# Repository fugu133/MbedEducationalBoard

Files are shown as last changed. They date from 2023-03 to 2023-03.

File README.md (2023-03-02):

# Mbed Educational Board
マイコン教育用として開発した基板になります．  
ベースは[mbed LPC1768](https://os.mbed.com/platforms/mbed-LPC1768/)でmbed OSを使ってプロトタイピング開発が可能です.  

サイズが75mm x 55mmの基板に以下の機能が搭載されています．
* タクトスイッチ x4
* アナログボリューム x3
* 完全絶縁のモータドライバ x2
* 6軸IMUセンサ x1
* トランスデューサ x1
* USBコネクタ x1
* GPIO x5 (内2つはI2C)

初学者向けに周辺機器を動かすための[ドライバ](https://github.com/fugu133/MbedEducationalBoard/tree/main/mbed/flib)を用意しているので簡単に扱えるかと思います．

比較的簡単にはんだ付けができるよう一部モジュール基板を使用しています．  
この基板一枚で簡単なロボットも作ることができます！



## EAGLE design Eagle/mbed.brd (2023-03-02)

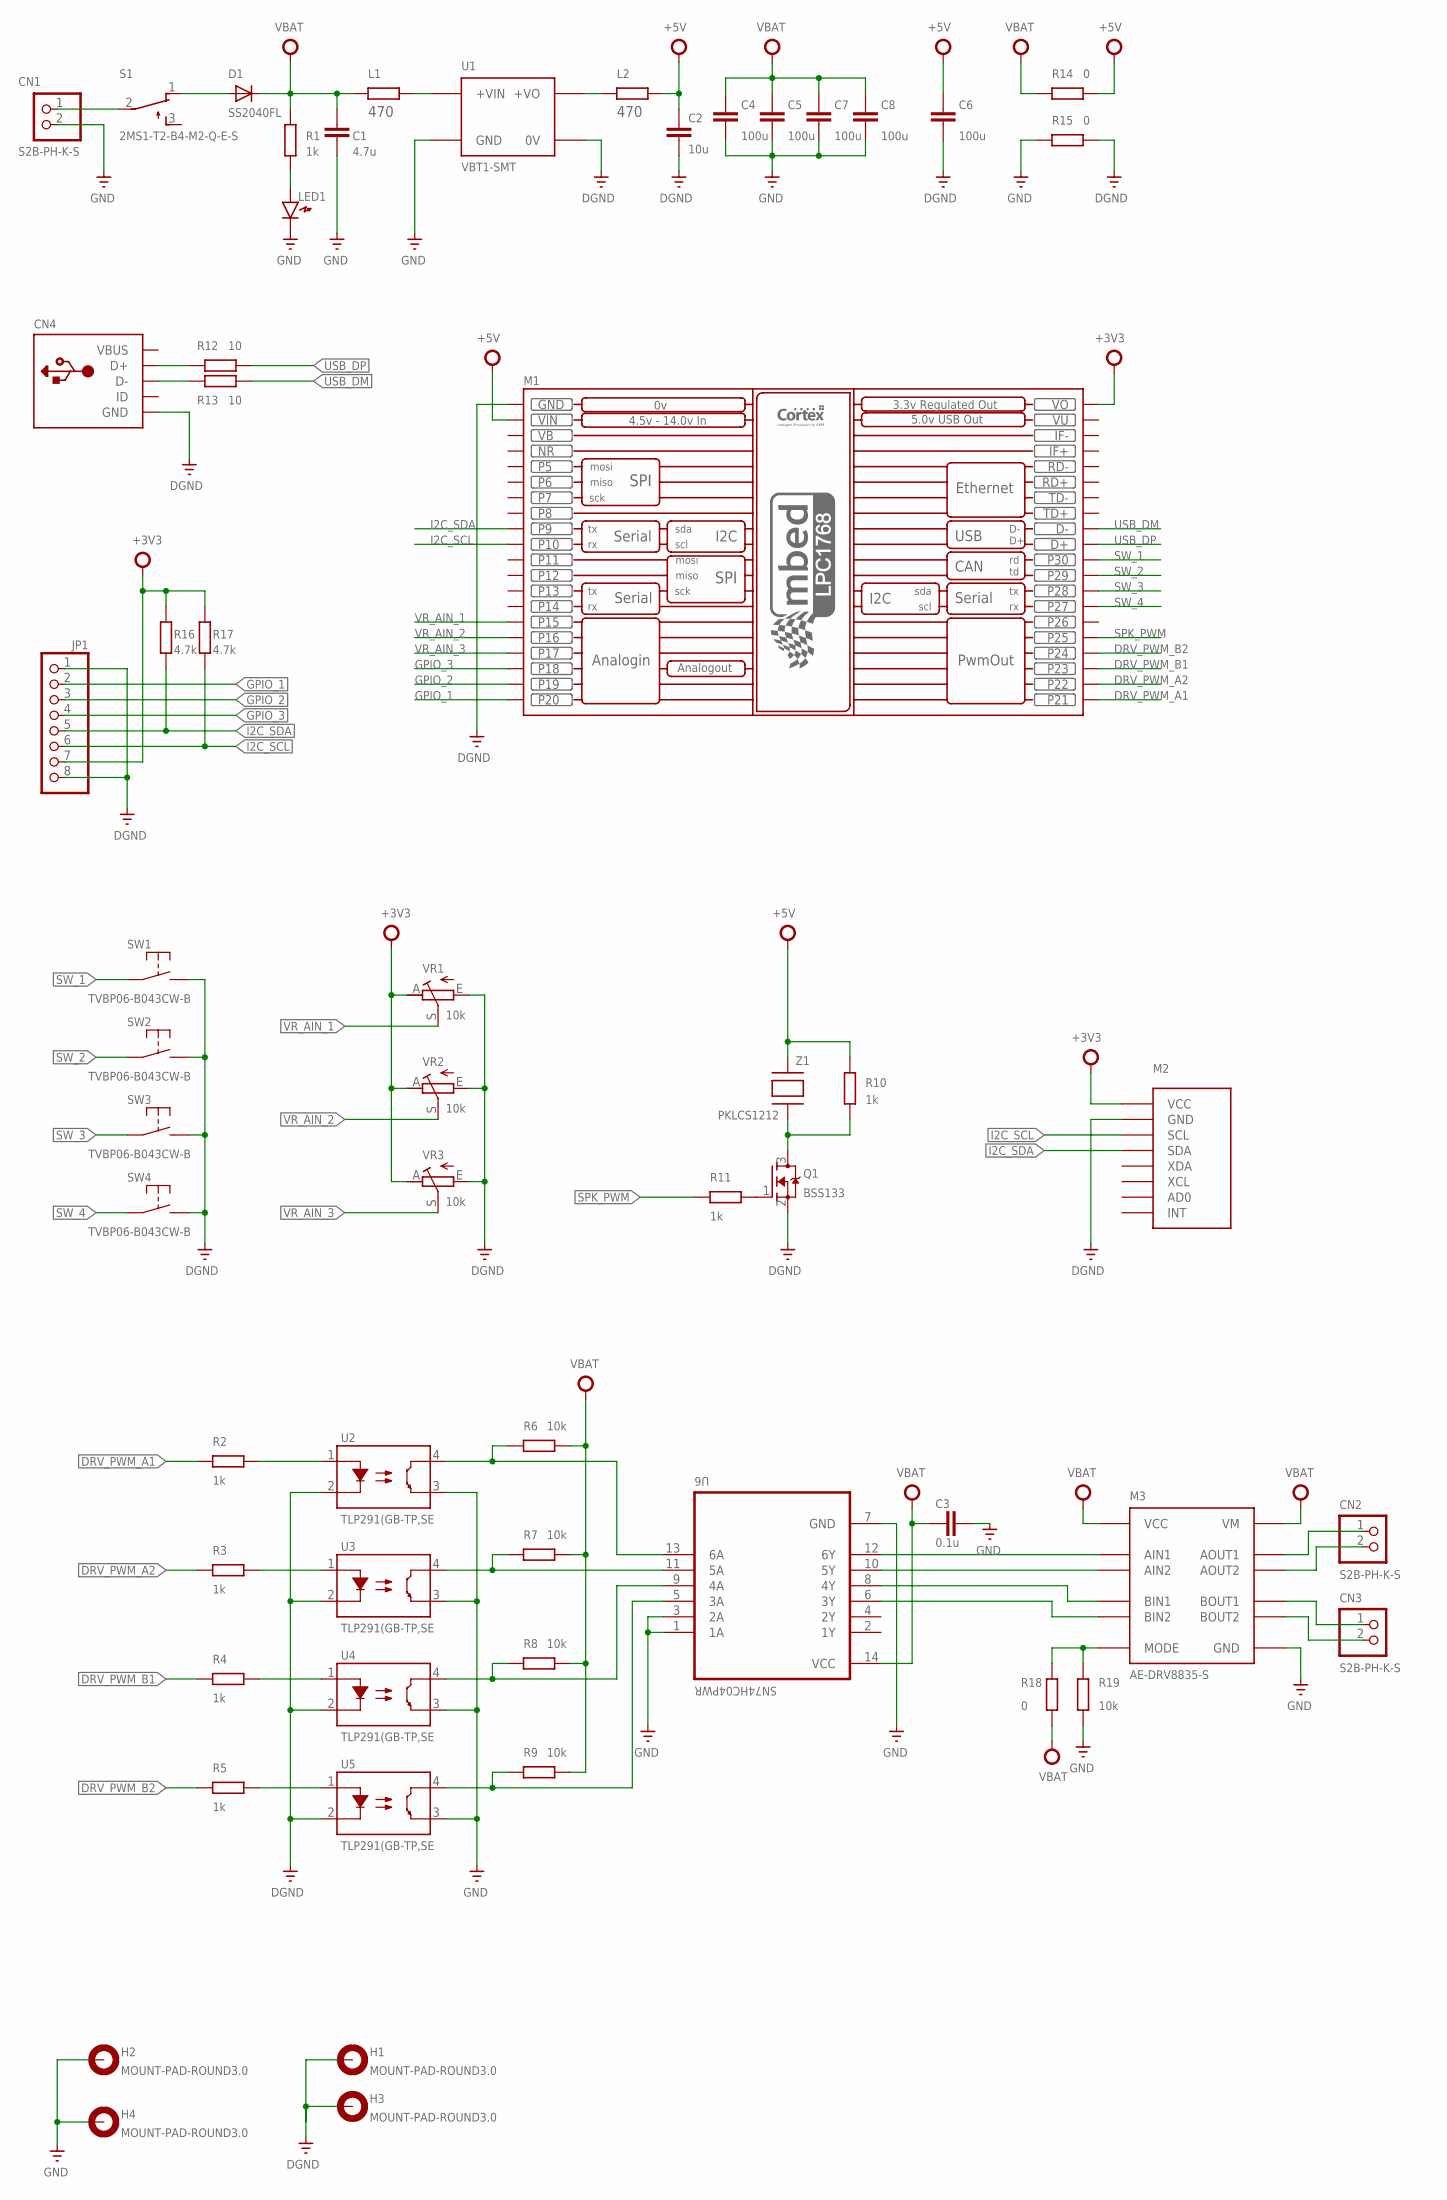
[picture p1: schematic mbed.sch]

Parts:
C1: 4.7u; C0603K
C2: 10u; C0603K
C3: 0.1u; C0603K
C4, C5, C6, C7, C8: 100u; C1206K
CN1, CN2, CN3: S2B-PH-K-S; JST-PH-2-THM-RA
CN4: USBMINIB; USB-MINIB
D1: SS2040FL; SOD-123
H1, H2, H3, H4: MOUNT-PAD-ROUND3.0; 3,0-PAD
JP1: PINHD-1X8BIG; 1X08-BIG
L1, L2: 470; R0603
LED1: LED_1608
M1: MBED_NXP_LPC1768; MBED-KIT
M2: MPU6050(GY-521); MPU6050
M3: AE-DRV8835-S; DIL12
Q1: BSS133; SOT23
R1, R2, R3, R4, R5, R10, R11: 1k; R0603
R6, R7, R8, R9, R19: 10k; R0603
R12, R13: 10; R0603
R14, R15, R18: 0; R0603
R16, R17: 4.7k; R0603
S1: 2MS1-T2-B4-M2-Q-E-S; TL3XPO
SW1, SW2, SW3, SW4: TVBP06-B043CW-B; SW1
U1: VBT1-SMT
U2, U3, U4, U5: TLP291(GB-TP,SE; SOIC127P700X220-4N
U6: SN74HC04PWR; SOP65P640X120-14N
VR1, VR2, VR3: 10k; VR-BOURNS
Z1: PKLCS1212

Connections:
+3V3: JP1.7, M1.VOUT (VO), M2.P$1 (VCC), R16.2, R17.2, VR1.A, VR2.A, VR3.A
+5V: C2.1, C6.1, L2.2, M1.VIN, R10.2, R14.1, Z1.P$2
DGND: C2.2, C6.2, CN4.GND, H1.B3,0, H3.B3,0, JP1.1, JP1.8, M1.GND, M2.P$2 (GND), Q1.2 (S), R15.1, SW1.P$2 (S), SW2.P$2 (S), SW3.P$2 (S), SW4.P$2 (S), U1.P$4 (0V), U2.2 (C), U3.2 (C), U4.2 (C), U5.2 (C), VR1.E, VR2.E, VR3.E
DRV_PWM_A1: M1.P$21 (P21), R2.2
DRV_PWM_A2: M1.P$22 (P22), R3.2
DRV_PWM_B1: M1.P$23 (P23), R4.2
DRV_PWM_B2: M1.P$24 (P24), R5.2
GND: C1.2, C3.2, C4.2, C5.2, C7.2, C8.2, CN1.2 (1), H2.B3,0, H4.B3,0, LED1.K, M3.P$6 (GND), R15.2, R19.2, U1.P$1 (GND), U2.3 (EMIT), U3.3 (EMIT), U4.3 (EMIT), U5.3 (EMIT), U6.1 (1A), U6.3 (2A), U6.7 (GND)
GPIO_1: JP1.2, M1.P$20 (P20)
GPIO_2: JP1.3, M1.P$19 (P19)
GPIO_3: JP1.4, M1.P$18 (P18)
I2C_SCL: JP1.6, M1.P$10 (P10), M2.P$3 (SCL), R17.1
I2C_SDA: JP1.5, M1.P$9 (P9), M2.P$4 (SDA), R16.1
unnamed: L2.1, U1.P$5 (+VO)
unnamed: CN1.1 (2), S1.2
unnamed: LED1.A, R1.1
unnamed: Q1.3 (D), R10.1, Z1.P$1
unnamed: Q1.1 (G), R11.1
unnamed: M3.P$8 (BIN1), U6.8 (4Y)
unnamed: M3.P$7 (BIN2), U6.6 (3Y)
unnamed: M3.P$10 (AIN1), U6.12 (6Y)
unnamed: CN2.1 (2), M3.P$2 (AOUT1)
unnamed: CN2.2 (1), M3.P$3 (AOUT2)
unnamed: CN3.1 (2), M3.P$4 (BOUT1)
unnamed: CN3.2 (1), M3.P$5 (BOUT2)
unnamed: R5.1, U5.1 (A)
unnamed: R4.1, U4.1 (A)
unnamed: R3.1, U3.1 (A)
unnamed: R2.1, U2.1 (A)
unnamed: R9.2, U5.4 (COL), U6.5 (3A)
unnamed: R8.1, U4.4 (COL), U6.9 (4A)
unnamed: R7.1, U3.4 (COL), U6.11 (5A)
unnamed: R6.1, U2.4 (COL), U6.13 (6A)
unnamed: D1.A, S1.1 (O)
unnamed: M3.P$11 (MODE), R18.1, R19.1
unnamed: CN4.D-, R13.1
unnamed: CN4.D+, R12.1
unnamed: L1.2, U1.P$2 (+VIN)
unnamed: M3.P$9 (AIN2), U6.10 (5Y)
NR: M1.NR
SPK_PWM: M1.P$25 (P25), R11.2
SW_1: M1.P$30 (P30), SW1.P$1
SW_2: M1.P$29 (P29), SW2.P$1
SW_3: M1.P$28 (P28), SW3.P$1
SW_4: M1.P$27 (P27), SW4.P$1
USB_DM: M1.D-, R13.2
USB_DP: M1.D+, R12.2
VB: M1.VB
VBAT: C1.1, C3.1, C4.1, C5.1, C7.1, C8.1, D1.C, L1.1, M3.P$1 (VM), M3.P$12 (VCC), R1.2, R6.2, R7.2, R8.2, R9.1, R14.2, R18.2, U6.14 (VCC)
VBUS: CN4.VBUS
VR_AIN_1: M1.P$15 (P15), VR1.S
VR_AIN_2: M1.P$16 (P16), VR2.S
VR_AIN_3: M1.P$17 (P17), VR3.S
VU: M1.VU

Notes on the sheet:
SW1
SW2
SW3
SW4
TVBP06-B043CW-B

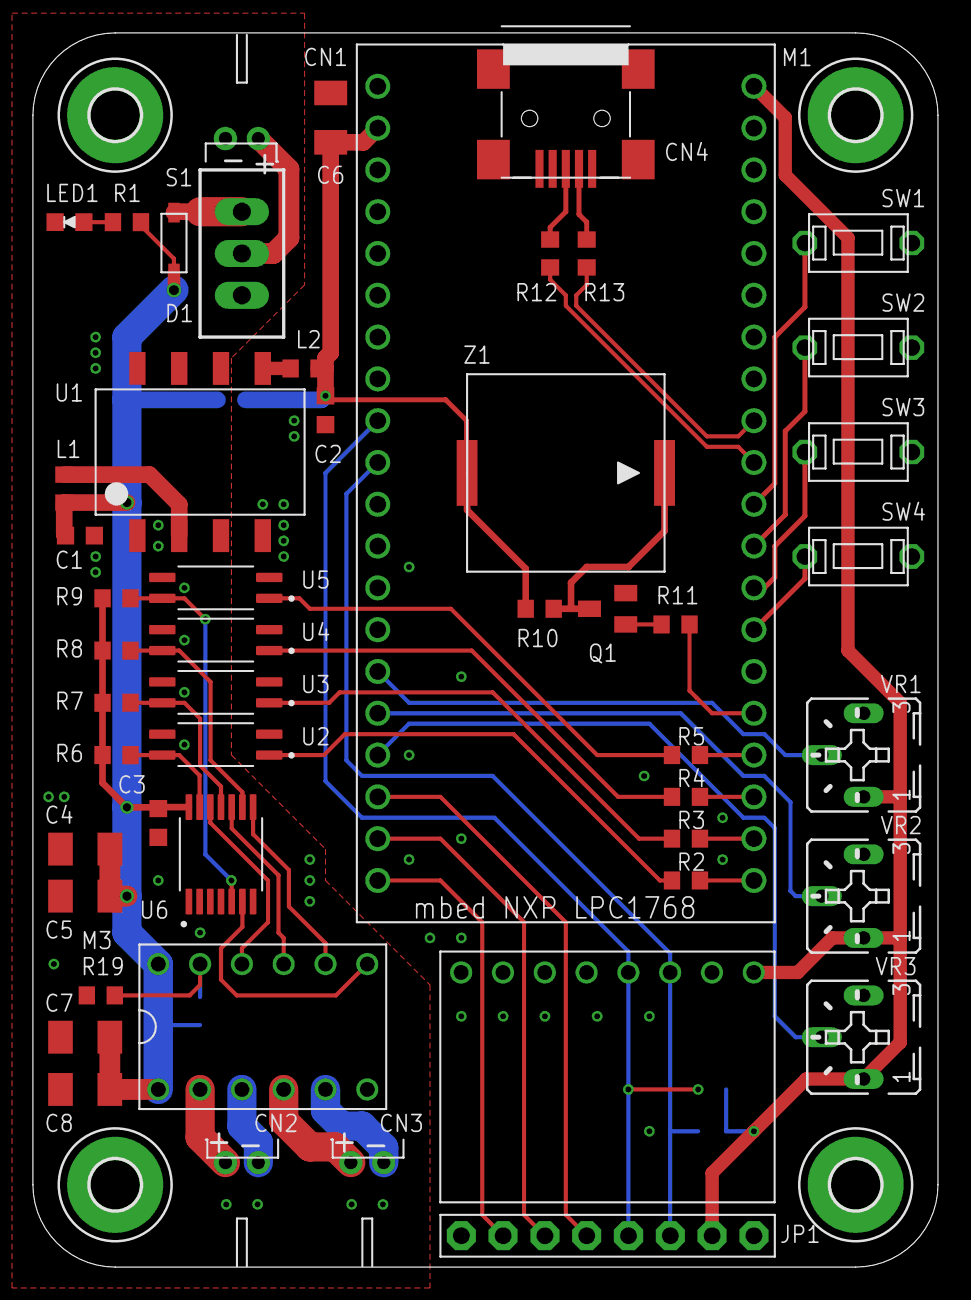
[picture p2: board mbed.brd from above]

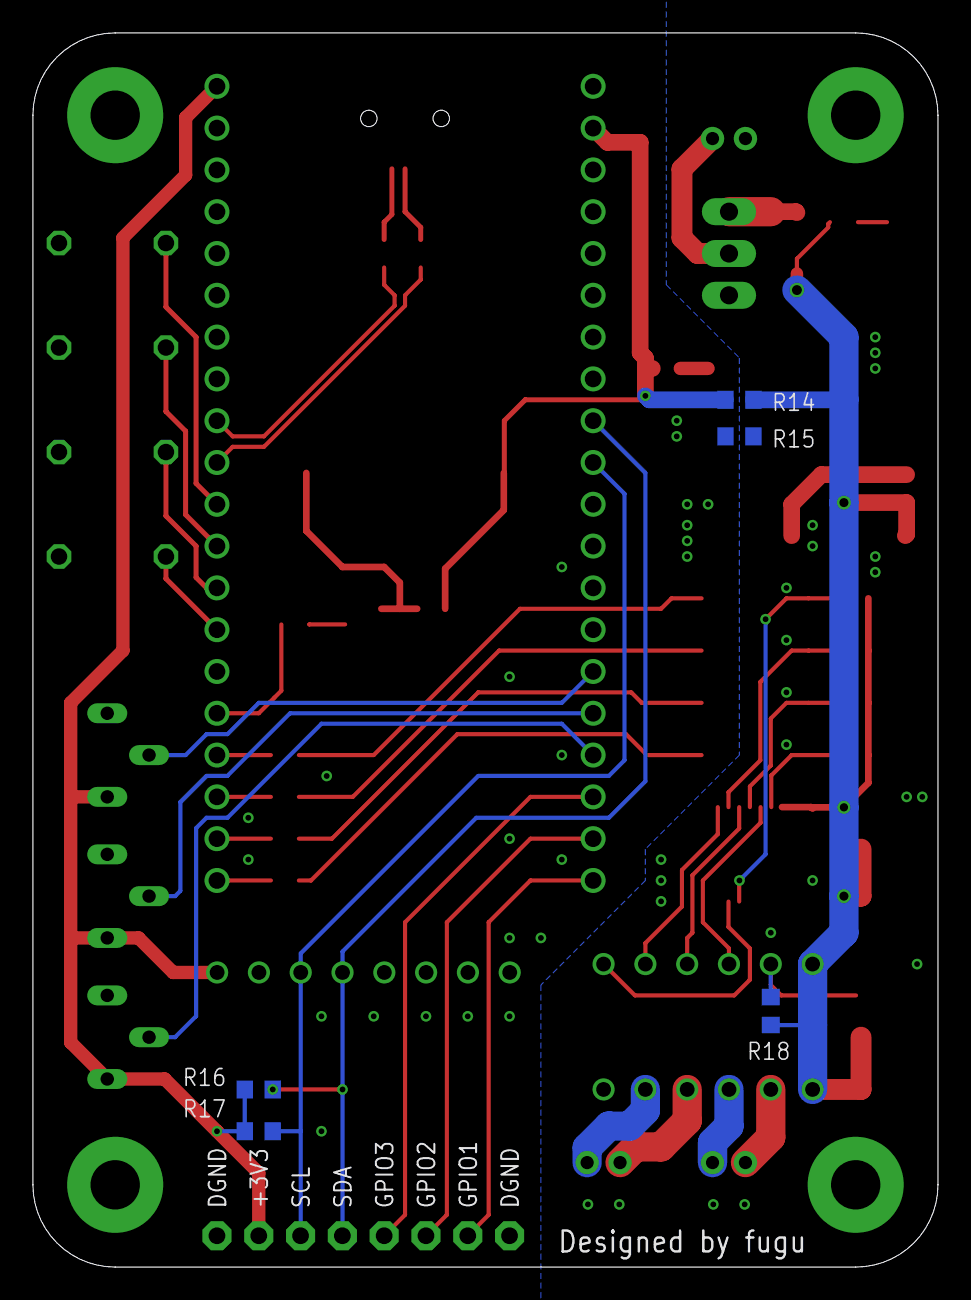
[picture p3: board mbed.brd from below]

Board: 2 copper layers, 55.0 x 75.0 mm, 59 parts (5 on the bottom side), 50 nets.

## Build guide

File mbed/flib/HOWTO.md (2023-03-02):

# README

## 概要

倒立振子用基板の機能を最低限使用できるようになるライブラリです．  
これをベースに倒立振子を開発するのも良し，自分で一から開発するのも良しです．  

<br>

## 使い方

flibを使うために以下の手順を行う必要があります．

1. flibをプロジェクトディレクトリ直下に置く
2. flib.hをインクルードする
3. 別途初期化が必要になるのでfugu::init()をメインループに入る前にコール

恐らく下記の様なコードになると思います．

~~~C++
#include "mbed.h"
#include "flib/flib.h"

int main() {
    fugu::init();
    while(1) {

    }
}
~~~

本ライブラリは基本的に`fugu`名前空間に記述しています．  
`using namespace fugu`をしてもいいですが，もしかしたら名前衝突するかもしれません．  

予約済みなIOピンはpin.hに定義済みです．  

<br>

## ペリフェラルドライバについて

基板上に置かれたペリフェラルを簡単に扱う為のドライバライブラリです．  
最低限の昨日が実装されています．  

### 1. IMUSensor

IMUセンサであるMPU6050を利用する為のドライバライブラリです．  
加速度[m/s]と角速度[deg/s]を取得出来ます．  

### 2. MotorDriver

2chモータードライバであるDRV8835を1ch操作する為のドライバライブラリです．  
2つインスタンスを作成することで2chフルに扱うことができます．  
動作モードはIN/INモードです．  

### 3. SwitchStatus

正論理，負論理を考慮してスイッチの状態を取得するドライバライブラリです．  
ソフトウェア的にチャタリングイレイズもできます．  

### 4. Tone

ピエゾスピーカーで発音するドライバライブラリです．  
音階指定はMIDIに準拠して行います．  

<br>

## Special Thanks

パワーマネジメントにMichael Wei氏のPowerControlライブラリを使用しています．

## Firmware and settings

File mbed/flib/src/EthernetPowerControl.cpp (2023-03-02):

#include "../inc/PowerControl/EthernetPowerControl.h"
 
static void write_PHY (unsigned int PhyReg, unsigned short Value) {
   /* Write a data 'Value' to PHY register 'PhyReg'. */
   unsigned int tout;
   /* Hardware MII Management for LPC176x devices. */
   LPC_EMAC->MADR = DP83848C_DEF_ADR | PhyReg;
   LPC_EMAC->MWTD = Value;
 
   /* Wait utill operation completed */
   for (tout = 0; tout < MII_WR_TOUT; tout++) {
      if ((LPC_EMAC->MIND & MIND_BUSY) == 0) {
         break;
      }
   }
}
 
static unsigned short read_PHY (unsigned int PhyReg) {
   /* Read a PHY register 'PhyReg'. */
   unsigned int tout, val;
 
   LPC_EMAC->MADR = DP83848C_DEF_ADR | PhyReg;
   LPC_EMAC->MCMD = MCMD_READ;
 
   /* Wait until operation completed */
   for (tout = 0; tout < MII_RD_TOUT; tout++) {
      if ((LPC_EMAC->MIND & MIND_BUSY) == 0) {
         break;
      }
   }
   LPC_EMAC->MCMD = 0;
   val = LPC_EMAC->MRDD;
   
   return (val);
}
 
void EMAC_Init()
{
  unsigned int tout,regv;
  /* Power Up the EMAC controller. */
  Peripheral_PowerUp(LPC1768_PCONP_PCENET);
  
  LPC_PINCON->PINSEL2 = 0x50150105;
  LPC_PINCON->PINSEL3 &= ~0x0000000F;
  LPC_PINCON->PINSEL3 |= 0x00000005;
 
  /* Reset all EMAC internal modules. */
  LPC_EMAC->MAC1 = MAC1_RES_TX | MAC1_RES_MCS_TX | MAC1_RES_RX | MAC1_RES_MCS_RX |
             MAC1_SIM_RES | MAC1_SOFT_RES;
  LPC_EMAC->Command = CR_REG_RES | CR_TX_RES | CR_RX_RES;
 
  /* A short delay after reset. */
  for (tout = 100; tout; tout--);
 
  /* Initialize MAC control registers. */
  LPC_EMAC->MAC1 = MAC1_PASS_ALL;
  LPC_EMAC->MAC2 = MAC2_CRC_EN | MAC2_PAD_EN;
  LPC_EMAC->MAXF = ETH_MAX_FLEN;
  LPC_EMAC->CLRT = CLRT_DEF;
  LPC_EMAC->IPGR = IPGR_DEF;
 
  /* Enable Reduced MII interface. */
  LPC_EMAC->Command = CR_RMII | CR_PASS_RUNT_FRM;
 
  /* Reset Reduced MII Logic. */
  LPC_EMAC->SUPP = SUPP_RES_RMII;
  for (tout = 100; tout; tout--);
  LPC_EMAC->SUPP = 0;
 
  /* Put the DP83848C in reset mode */
  write_PHY (PHY_REG_BMCR, 0x8000);
 
  /* Wait for hardware reset to end. */
  for (tout = 0; tout < 0x100000; tout++) {
    regv = read_PHY (PHY_REG_BMCR);
    if (!(regv & 0x8000)) {
      /* Reset complete */
      break;
    }
  }
}
 
 
void PHY_PowerDown()
{
    if (!Peripheral_GetStatus(LPC1768_PCONP_PCENET))
        EMAC_Init(); //init EMAC if it is not already init'd
    
    unsigned int regv;
    regv = read_PHY(PHY_REG_BMCR);
    write_PHY(PHY_REG_BMCR, regv | (1 << PHY_REG_BMCR_POWERDOWN));
    regv = read_PHY(PHY_REG_BMCR);
    
    //shouldn't need the EMAC now.
    Peripheral_PowerDown(LPC1768_PCONP_PCENET);
    
    //and turn off the PHY OSC
     LPC_GPIO1->FIODIR |= 0x8000000;
     LPC_GPIO1->FIOCLR = 0x8000000;
}
 
void PHY_PowerUp()
{   
    if (!Peripheral_GetStatus(LPC1768_PCONP_PCENET))
        EMAC_Init(); //init EMAC if it is not already init'd
        
    LPC_GPIO1->FIODIR |= 0x8000000;
    LPC_GPIO1->FIOSET = 0x8000000;
    
    //wait for osc to be stable
    ThisThread::sleep_for(200);
    
    unsigned int regv;
    regv = read_PHY(PHY_REG_BMCR);
    write_PHY(PHY_REG_BMCR, regv & ~(1 << PHY_REG_BMCR_POWERDOWN));
    regv = read_PHY(PHY_REG_BMCR);
}
 
void PHY_EnergyDetect_Enable()
{
    if (!Peripheral_GetStatus(LPC1768_PCONP_PCENET))
        EMAC_Init(); //init EMAC if it is not already init'd
        
    unsigned int regv;
    regv = read_PHY(PHY_REG_EDCR);
    write_PHY(PHY_REG_BMCR, regv | (1 << PHY_REG_EDCR_ENABLE));
    regv = read_PHY(PHY_REG_EDCR);   
}
 
void PHY_EnergyDetect_Disable()
{
    if (!Peripheral_GetStatus(LPC1768_PCONP_PCENET))
        EMAC_Init(); //init EMAC if it is not already init'd
    unsigned int regv;
    regv = read_PHY(PHY_REG_EDCR);
    write_PHY(PHY_REG_BMCR, regv & ~(1 << PHY_REG_EDCR_ENABLE));
    regv = read_PHY(PHY_REG_EDCR);   
}

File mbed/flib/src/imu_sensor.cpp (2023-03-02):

#include "../inc/imu_sensor.h"
#include "algorithm"
#include "iterator"
#include <cmath>
#include <cstdint>

namespace fugu {

IMUSensor::IMUSensor(I2C *i2c, uint8_t addr)
    : dev_i2c(i2c), dev_addr(addr),
      gyro_coeff(scale_convert(GyroScale::RANGE_250DPS)), gyro_bias{0},
      accel_coeff(scale_convert(AccelScale::RANGE_2G)), accel_bias{0} {
  write_byte(Register::PWR_MGMT_1, 0x00);
}

IMUSensor::IMUSensor(PinName sda, PinName scl, uint8_t addr)
    : dev_i2c(new I2C(sda, scl)), dev_addr(addr),
      gyro_coeff(scale_convert(GyroScale::RANGE_250DPS)), gyro_bias{0},
      accel_coeff(scale_convert(AccelScale::RANGE_2G)), accel_bias{0} {
  write_byte(Register::PWR_MGMT_1, 0x00);
}

bool IMUSensor::available() {
  uint8_t data = read_byte(Register::WHO_AM_I);
  return data == dev_addr >> 1;
}

bool IMUSensor::set_gyro_scale(GyroScale scale) {
  bool ack =
      write_byte(Register::GYRO_CONFIG, static_cast<uint8_t>(scale) << 3);
  gyro_coeff = scale_convert(scale);

  return ack;
}

bool IMUSensor::set_accel_scale(AccelScale scale) {
  bool ack =
      write_byte(Register::ACCEL_CONFIG, static_cast<uint8_t>(scale) << 3);
  accel_coeff = scale_convert(scale);

  return ack;
}

void IMUSensor::set_gyro_bias(const float (&bias)[3]) {
  std::copy(std::begin(bias), std::end(bias), std::begin(gyro_bias));
}

void IMUSensor::set_accel_bias(const float (&bias)[3]) {
  std::copy(std::begin(bias), std::end(bias), std::begin(accel_bias));
}

bool IMUSensor::read_angular_rate(float (&angular_rate)[3]) {
  uint8_t raw_data[6] = {0};
  bool ack;

  ack = !read_byte_array(Register::GYRO_XOUT_H, 6, raw_data);

  for (uint32_t i = 0; i < axsis_num; i++)
    angular_rate[i] =
        convert_angular_rate(raw_data + i * sizeof(int16_t)) - gyro_bias[i];

  return ack;
}

bool IMUSensor::read_acceleration(float (&acceleration)[3]) {
  uint8_t raw_data[6] = {0};
  bool ack;

  ack = !read_byte_array(Register::ACCEL_XOUT_H, 6, raw_data);

  for (uint32_t i = 0; i < axsis_num; i++)
    acceleration[i] =
        convert_acceleration(raw_data + i * sizeof(int16_t)) - accel_bias[i];

  return ack;
}

uint8_t IMUSensor::read_byte(uint8_t reg) {
  char write_data = reg;
  char read_data;

  dev_i2c->write(dev_addr, &write_data, 1, 1);
  dev_i2c->read(dev_addr, &read_data, 1, 0);

  return read_data;
}

bool IMUSensor::read_byte_array(uint8_t start_reg, uint8_t length,
                                uint8_t output[]) {
  char write_data = start_reg;

  dev_i2c->write(dev_addr, &write_data, 1, 1);
  return dev_i2c->read(dev_addr, reinterpret_cast<char *>(output), length, 0);
}

bool IMUSensor::write_byte(uint8_t reg, uint8_t data) {
  char write_data[2] = {reg, data};

  return dev_i2c->write(dev_addr, write_data, 2, 0);
}
} // namespace fugu

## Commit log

2023-03-02 CADデータを追加
    [mbed.brd, mbed.sch]
2023-03-02 PCBのガーバーイメージを追加
2023-03-02 ペリフェラルドライバを追加
2023-03-02 文章文章を修正
